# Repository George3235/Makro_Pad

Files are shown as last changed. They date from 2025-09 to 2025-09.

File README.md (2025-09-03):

# 3×3 MacroPad för ESP32-S3 (Waveshare ESP32-S3 Zero)

Volymratt (rotary), två layers (Numbers & Shortcuts) och HID-tangenter

## Översikt

Detta är ett kompakt 3×3 MacroPad med ESP32-S3 som agerar USB-HID-tangentbord samt Consumer Control (volym m.m.).
En rotary encoder (KY-040) styr volym upp/ner; knapptryck på encodern ger mute/unmute, dubbeltryck växlar layer (Numbers ↔ Shortcuts), och långtryck är reserverat för ett tredje läge (Applications, för framtida funktioner).

Projektet är gjort för Windows-genvägar i Shortcut-lagret, men koden är enkel att ändra för andra OS.

## Funktioner

### Två layers

- Numbers: siffertangenter 1–9 i klassisk telefonpad-ordning

- Shortcuts (Windows): Copy, Paste, Cut, Undo, Select All, New Tab, Screenshot (Win+Shift+S), Rename (F2), Play/Pause (media)

### Rotary encoder

- Vrid höger/vänster: Volym +/–

- Klick: Mute/Unmute

- Långtryck: Växla layer (Numbers ↔ Shortcuts)

#### Anti-ghosting via 1N4148-dioder på varje switch i matrisen

#### Minimal extern hårdvara (använder interna pull-ups)

---------------------------------------------------------------

## Komponenter (BOM)
| Description | Amount |
|---| ---|
| Waveshare ESP32-S3 Zero (Esp-S3-WROOM-1/-1U-modul) | 1 |
| KY-040 Rotary Encoder (med tryckknapp) | 1 |
| Mekaniska brytare (MX-kompatibla) | 9 |
| Diod 1n4148 (anti-ghosting, en per brytare) | 9 |
| Case (3D printad) | 1 |
| Skruva med längd 8 mm | 4 |

-------------------------------------------------------------------

## Dator-setup

### Val av IDE
- Arduino IDE (enkelt att komma igång)
- PlatformIO (mer avancerat/repovänligt, valfritt)

### Snabbguide 
1. Installera ESP32 stöd i Arduino IDE (Boards Manager, Espressif Systems, v3.x)
2. Välj kort Waveshare ESP32-S3-Zero
3. USB-inställningar i ***Tools***:
    - `USB CDC On Boot: Enable` 
    - `USB Mode: Default / TinyUSB`
    - `PSRAM: enligt din modul`
    - `Upload Speed: 921600` (ev. 460800 om det strular)
4. Anslut med USB-C, kompilera & ladda upp.
> [!WARNING]
> ***Ingen port?*** Håll ***BOOT***, tryck ***RESET***, släpp >***BOOT*** (download-mode). Välj rätt COM-port och försök igen.
-------------------------------------------------------------------

## Kopplingar (pins & dioder)
### Matris

Koden skannar ***kolumner aktiva låga*** (sätter kolumn ***LOW*** en i taget) och läser rader med `INPUT_PULLUP`.
| Funktion | ESP32-S3 | Kommentar |
| ---| ---| ---|
| Col 0 | 1 | Output (normal HIGH, aktiv LOW) |
| Col 1 |  2 | Output (normal HIGH, aktiv LOW) |
| Col 2 | 12 | Output (normal HIGH, aktiv LOW) |
| Row 0 | 3  | Input Pull-Up |
| Row 1 | 4  | Input Pull-Up |
| Row 2 | 5  | Input Pull-Up |

> [!IMPORTANT]
> ***Diod-riktning***: Rader är höga via pull-up och kolumnen dras  ***LOW*** när den skannas. <br>
> Strömmen ska går rad -> kolumn när knappen trycks. <br>
> Sätt anod rad, katod (ringen) mot kolumn. 
> Koppling: `Row (anod) ->|-(katod) -> Switch -> Col`.

### Encoder
| Funktion |  ESP32-S3 GPIO |
| --- | --- |
| ENC_DT | 6 |
| ENC_CLK | 7 |
| ENC_SW (knapp) | 8 |

## Keymaps (layout per layer)
### Numbers
``` 
7 8 9 
4 5 6 
1 2 3 
 ```
Koden skickar vanliga tecken `1–9` enligt matrisens `[rad][kolumn]`.

### Shortcuts (Windows)
```
Copy        Paste       Cut
Undo        Select All  New Tab
Screenshot  Rename(F2)  Play/Pause
```

> OBS: Genvägarna är anpassade för Windows. På macOS/Linux behöver du troligen mappa om tangenterna (i Shortcuts::send).

## Encoder-kontroller

- Vrid medurs: Volym upp

- Vrid moturs: Volym ned

- Klick: Mute/Unmute

- Långtryck (~800 ms): Växla layer (Numbers ↔ Shortcuts)

## Firmwarestruktur
```
/src eller / (beroende på IDE)
│
├─ Config.h            → pinnar, matris, keymap, LED, EEPROM_SIZE
├─ HID_usages.h        → HID-usage IDs för volym ± (säkerställs i koden)
├─ State_machine.h/.cpp→ enum State { NUMS, SHORT_CUTS, APPLICATIONS }, set toggle/current
├─ Shortcuts.h/.cpp    → Windows-genvägar, samt Consumer Control Play/Pause
├─ Encoder.h/.cpp      → Volym via vridning, klick/dubbelklick/långtryck
└─ main .ino/.cpp      → init USB HID, skanna matris, ropa på rätt funktion per layer
```

- `USBHIDKeyboard` och `USBHIDConsumerControl` (TinyUSB) används för tangent- och mediaknappar.

- `EEPROM` är initierad; storlek 9 (kan användas senare för att spara t.ex. valt layer).

----------------------------------------------------------------------------------

## Bygga & flasha (Arduino IDE)

1. Installera ESP32-stöd i Boards Manager (Espressif Systems, v3.x rekommenderas).

2. Välj kort: ESP32S3 Dev Module (eller Waveshare ESP32-S3-Zero om du har den installerad).

3. Viktiga menyalternativ (Tools):

    - `USB CDC On Boot: Enabled`

    - `USB Mode: Default / TinyUSB`

    - `PSRAM: enligt ditt modul-utförande (ofta “OPI PSRAM” på S3 Zero)`

    - `Upload Speed: 921600 (eller 460800 om du har strul)`

4. Kablaget: Anslut S3 via USB-C direkt till datorn.

5. Kompilera & ladda upp. Efter flash ska en ny HID-enhet dyka upp (tangentbord + consumer control).

> Om porten inte syns: håll nere BOOT och tryck RESET, släpp RESET, släpp BOOT (sätter S3 i download-mode). Välj rätt COM-port och försök igen.

## 3D-Filer (CAD & STL)
Alla 3D-filer för chassit finns i mappen `3D_Files` i repot. <br>

### Innehåll: 
- `Topppen_Done` - övre skal med platta för MX-switchar
- `Bottom` - underdel

### Utskriftrekommendationer: 
- Material: PLA eller PETG
- Lagerhöjg : ~0.2 mm, 3 väggar, 20-30 % infill
- Stöd: endast där det behöver (vänd undersidan nedåt)
- Toleranser: hål för MX-switchar är dimensionerade nära 14x14 mm; finjustera skala/tolerans vid behov beroende på skrivare

------------------------------------
## Galleri
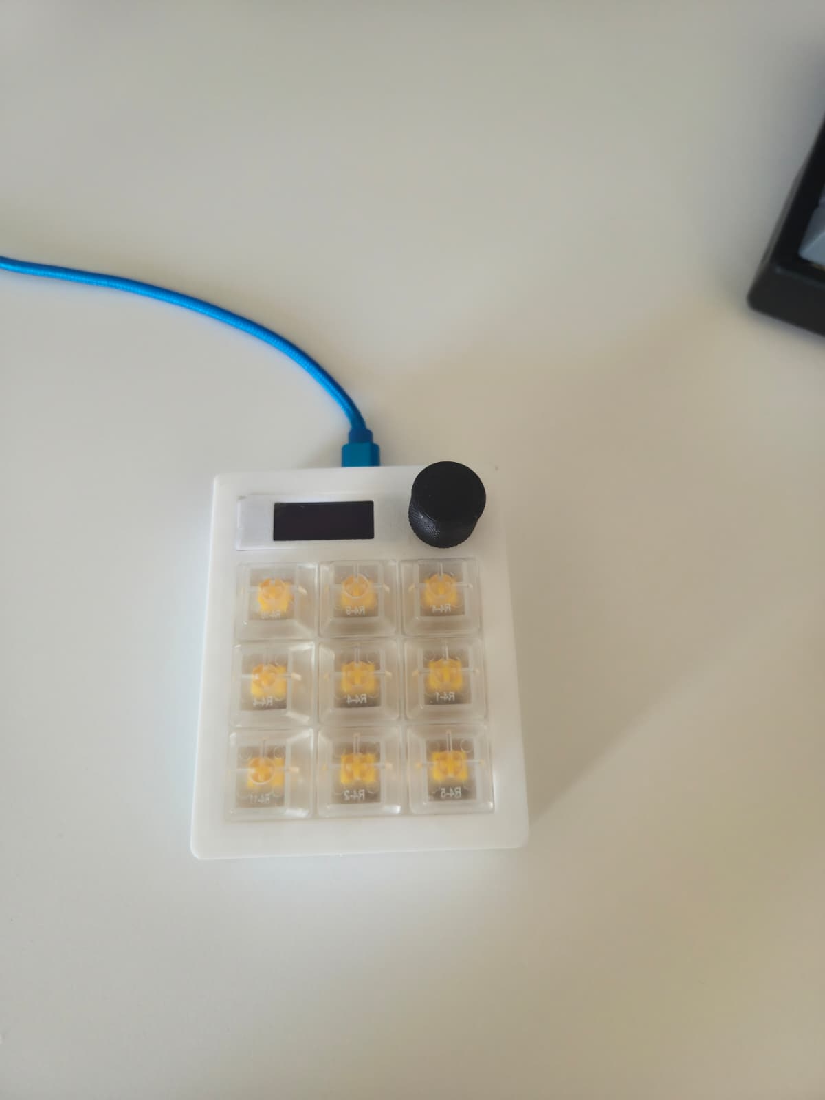
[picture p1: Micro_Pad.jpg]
MacroPad – färdig


## License
MIT © 2025 George Saba — se [LICENSE](./LICENSE).

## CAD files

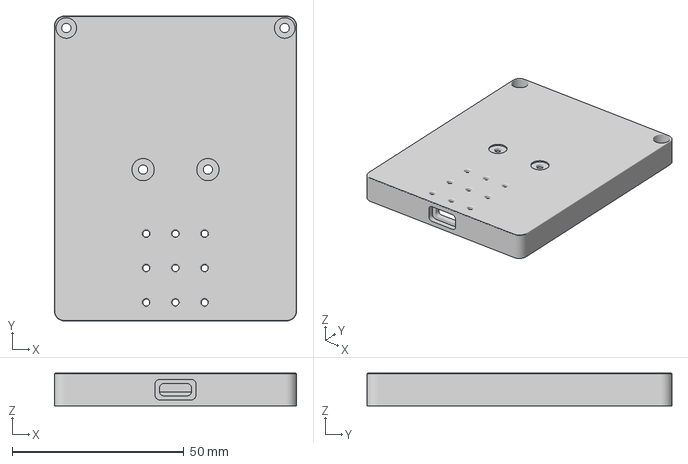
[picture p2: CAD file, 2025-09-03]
3D_Files/Bottom.3mf
70.5 x 88.8 x 9.50 mm

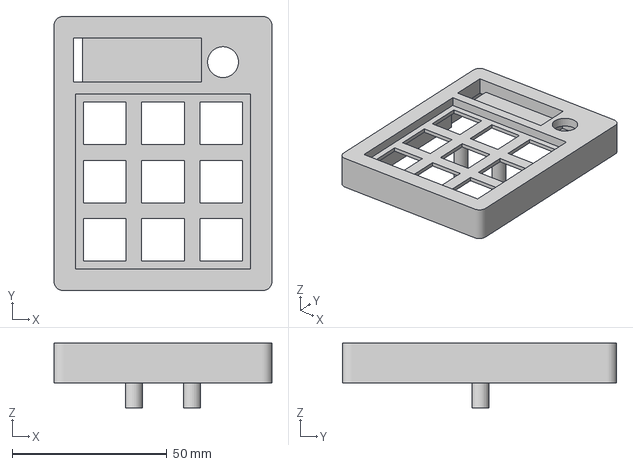
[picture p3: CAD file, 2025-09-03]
3D_Files/Toppen_Done.3mf
70.5 x 88.8 x 21.0 mm

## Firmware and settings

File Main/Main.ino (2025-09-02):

#include "USB.h"
#include "USBHIDKeyboard.h"
#include "USBHIDConsumerControl.h"
#include <EEPROM.h>

#include "Config.h"        // pinnar, keymap, LED_PIN, EEPROM_SIZE
#include "State_machine.h"
#include "Encoder.h"
#include "Shortcuts.h"

// --- Skapa HID-objekten först ---
USBHIDKeyboard Keyboard;
USBHIDConsumerControl Consumer;

// --- Shortcuts-hjälpare (Windows-only) ---
Shortcuts shortcuts(Keyboard, &Consumer);

// --- Encoder (äger din StateMachine inuti sig) ---
EncoderHandler encoder(Consumer);

// --- 3x3 mapping för SHORT_CUTS-läget ---
static const Shortcut shortcutsMap[3][3] = {
  { SC_COPY,       SC_UNDO,      SC_SCREENSHOT        },  // rad 0
  { SC_PASTE,       SC_SELECT_ALL, SC_RENAME    },  // rad 1
  { SC_CUT, SC_NEW_TAB,       SC_PAUS       }   // rad 2
};

// --- Hjälpfunktion: skicka rätt sak beroende på nuvarande State ---
static inline void handleKeyPress(uint8_t r, uint8_t c) {
  State st = encoder.stateMachine.current();
  if (st == State::NUMS) {
    // Siffror via keymap
    Keyboard.print(keymap[r][c]);
  } else {
    // Genvägar (Windows): copy/paste/screenshot/URL/play-pause osv.
    shortcuts.send(shortcutsMap[r][c]);
  }
}

void setup() {
  Serial.begin(115200);
  if (!EEPROM.begin(EEPROM_SIZE)) {
    Serial.println("EEPROM init failed!");
  }

  // Starta USB HID
  USB.begin();
  Keyboard.begin();
  Consumer.begin();   // viktigt för Consumer Control (play/pause m.m.)

  // Initiera matrispinnar
  for (uint8_t i = 0; i < 3; i++) {
    pinMode(cols[i], OUTPUT);
    digitalWrite(cols[i], HIGH);     // kolumner inaktiva = HIGH
    pinMode(rows[i], INPUT_PULLUP);  // rader input med pullup
  }

  // Initiera encoder (inkl. stateMachine.begin())
  encoder.begin();

  // LED
  pinMode(LED_PIN, OUTPUT);
  digitalWrite(LED_PIN, LOW);

  delay(500);  // ge USB lite tid att enumerera
}

void loop() {
  // Hantera encoder (vridning + knapp)
  encoder.update();

  // Skanna tangentmatrisen
  bool anyPressed = false;

  for (uint8_t c = 0; c < 3; c++) {
    // Aktivera kolumn (LOW) en i taget
    digitalWrite(cols[c], LOW);

    for (uint8_t r = 0; r < 3; r++) {
      if (digitalRead(rows[r]) == LOW) {  // knappen tryckt (aktiv låg)
        anyPressed = true;
        digitalWrite(LED_PIN, HIGH);

        // Skicka beroende på State (NUMS -> siffra, annars -> genväg)
        handleKeyPress(r, c);

        // Enkel debounce
        delay(200);

        // Vänta på release (så vi inte spammar vid hållning)
        while (digitalRead(rows[r]) == LOW) {
          delay(2);
          encoder.update();  // låt encoder funka under hållning
        }
      }
    }

    // Inaktivera kolumn
    digitalWrite(cols[c], HIGH);
  }

  if (!anyPressed) {
    digitalWrite(LED_PIN, LOW);
  }

  delay(2); // liten paus för att inte maxa CPU
}

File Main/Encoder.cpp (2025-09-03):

#include "Encoder.h"

EncoderHandler::EncoderHandler(USBHIDConsumerControl& consumer)
  : _consumer(consumer) {}

// Funktion som startar allting som har med Encoder att göra
void EncoderHandler::begin() {
    pinMode(ENC_DT,  INPUT_PULLUP);
    pinMode(ENC_CLK, INPUT_PULLUP);
    pinMode(ENC_SW,  INPUT_PULLUP);

    lastClk        = digitalRead(ENC_CLK);
    buttonState    = digitalRead(ENC_SW);
    lastButtonPress = 0;
    longPressFired  = false;

    // Initiera stateMachine 
    stateMachine.begin();
}

// Funktion för att uppdatera Encodern's state och egenskaper
void EncoderHandler::update() {
    // --- Rotary ---
    int clkState = digitalRead(ENC_CLK);
    if (clkState != lastClk) {
        uint32_t now = millis();
        if (now - lastChangeMs > 1) { // enkel debounce
            if (digitalRead(ENC_DT) != clkState) {
                volumeUp();
            } else {
                volumeDown();
            }
            lastChangeMs = now;
        }
        lastClk = clkState;
    }

    // --- Button (single/double/long) ---
    int sw = digitalRead(ENC_SW);

    // edge: HIGH -> LOW = press
    if (buttonState == HIGH && sw == LOW) {
        pressStart = millis();
        longPressFired = false;
    }

    // håll-koll: long press
    if (sw == LOW && !longPressFired) {
        if (millis() - pressStart > 800) { // 800 ms long-press
            onLongPress();
            longPressFired = true;
        }
    }

    // edge: LOW -> HIGH = release
    if (buttonState == LOW && sw == HIGH) {
        uint32_t now = millis();
        if (!longPressFired) {
            onClick();
        }
    }
    buttonState = sw;
}

// Om man vrider åt höger -> höjer volymen
void EncoderHandler::volumeUp() {
    _consumer.press(HID_USAGE_CONSUMER_VOLUME_INCREMENT); // från TinyUSB enum
    delay(2);
    _consumer.release();
}

// Om man vrider åt vänster -> Sänker volymen
void EncoderHandler::volumeDown() {
    _consumer.press(HID_USAGE_CONSUMER_VOLUME_DECREMENT); // från TinyUSB enum
    delay(2);
    _consumer.release();
}

// Om man trycker på Encodern's knapp snabbt -> Mute / Unmute
void EncoderHandler::onClick() {
  _consumer.press(HID_USAGE_CONSUMER_MUTE); 
  delay(2); 
  _consumer.release();
}


// Om användaren trycker en längre period ska den byta layer
void EncoderHandler::onLongPress() {
    stateMachine.toggle();
}

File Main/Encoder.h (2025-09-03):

#ifndef ENCODER_H
#define ENCODER_H

#include <Arduino.h>
#include "Config.h"
#include "USBHIDConsumerControl.h"  // innehåller TinyUSB HID-usage enum via beroenden
#include "State_machine.h"

class EncoderHandler {
public:
    explicit EncoderHandler(USBHIDConsumerControl& consumer);

    void begin();   // initiera pinnar
    void update();  // körs i loop()

    void onClick();       // singelklick
    void onLongPress();   // långtryck

    StateMachine stateMachine;   // Variabel av state machine 

private:
    USBHIDConsumerControl& _consumer;

    void volumeUp();
    void volumeDown();

    int lastClk = HIGH;
    uint32_t lastChangeMs = 0;
    bool isMuted = false;

    // knapp-state
    int buttonState = HIGH;
    uint32_t lastButtonPress = 0;
    uint32_t pressStart = 0;
    bool longPressFired = false;
};

#endif

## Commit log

2025-09-02 Fixade 2 States och testade allting så att allting fungerar rätt
    [Encoder.cpp, Main.ino]
2025-09-03 Filerna för 3D filer finns nu med
    [Bottom.3mf, Toppen_Done.3mf]
